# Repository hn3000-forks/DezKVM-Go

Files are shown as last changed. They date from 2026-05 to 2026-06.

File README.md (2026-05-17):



# DezKVM-Go

A mini KVM over USB device for onsite engineers to use their laptop to control headless computers or servers.

If you are looking for an IP-KVM solution, take a look at the [DezKVM](https://github.com/tobychui/DezKVM) Project!

## Features

- Small form factor , just 84 x 53 x 18mm
- Cheap & Easy to build, costing just under $20 USD per unit
- Fully featured software that do not require installing any apps
  - Live video and audio feeds
  - Paste box (host to remote computer through automatic virtual keyboard HID events)
  - Copy via OCR (remote to host computer through OCR image to text conversion) 
  - On-screen keyboard
  - Commonly used Hot-key and macros
  - Take Screenshots
- Advanced Settings
  - Invert mouse scroll wheel direction (for Windows / MacOS cross control)
  - Absolute / Relative mode for mouse
  - Mouse Jiggler
  
## Usage

1. Insert the DezKVM-Go host side USB port into your laptop using a USB type-C cable (located on the white / black side, depends on your device casing color)
2. Insert the DezKVM-Go remote side USB port and HDMI port into the remote server or computer you want to control (located on the orange side)
3. Visit the [DezKVM-Go control panel](https://tobychui.github.io/DezKVM-Go/) or if you are working online, start the usbkvm application and visit `https://localhost:8443/` using Chrome, Edge or any Chromium browsers that support Web-Serial API.

## Quick Start



## Building the Hardware

To build the hardware, you will need the following items

- A DezKVM-Go PCB (See the `PCB` folder and the `how-to-place-order` folder on how to order them )
  
- A MS2109 HDMI capture card (usually around $7 - 9 USD a pcs)
- A 3D printer (for the case, see `3D Models` folder)
- M3x10 screws x 2
- USB type-C cable x 2 and HDMI cable x 1

For details, see the PCB folder.

## Building the Software

There is no need to build anything since all of the control code of this system is written in vanilla js in the web front-end. However, this project do come with a Golang written https server in which if you have difficulties deploying a website with https , you can use that https server to deploy a locally hosted version of the DezKVM viewer.

To build the local version of DezKVM viewer, follow the instruction below.

```bash
cd ./src
go mod tidy
go build
```

*Note: you will also need to configure the CH9329 chip to use the 115200 baudrate for the front-end to work. Please follow the instructions in CH9329 datasheet to perform the baudrate change procedures before use.*

## Screenshots









[See more screenshots](https://github.com/tobychui/DezKVM-Go/wiki/Screenshots)

## DezKVM-Go Device

Here are a few photos on the device itself if you are interested.













### Generation 2 (MS2109S)

Due to shortage of MS2109, the HDMI capture card market are slowly shifting towards a new design of such capture card that uses MS2109S  (looks identical to the old MS2109 one, so it is hard to tell by just looking at the case of it),

In case you bought a HDMI capture card and realize it didn't fit because it is a MS2109S device, you can unscrew the metal case and use the bare PCB directly. Installation methods are as follows (notes: an additional 3D printed part and 3 x M2 x 5 screws are needed)

gen2-diff

### Buy a Ready-to-use Device

If you’d rather skip the build, I’ve put together some DezKVM Go devices that are ready to go. 

You can find them on my Tindie store (limited availability):

https://www.tindie.com/products/tobychui/dezkvm-go-kvm-over-usb-device/

## License

Software: GPLv3

Hardware: CC BY-NC-ND

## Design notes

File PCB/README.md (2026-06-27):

## Making your own DezKVM-GO Hardware

Making your DezKVM Go hardware is not difficult. What you need is to send the PCB to print. If you have the budget, you can even go the full PCBA route and make a ready to use product with the help of [NextPCB](https://www.nextpcb.com/?code=tobychui/C) (sponsor of this project)

### PCB Photoshoots







That cutout is for the MS2109 HDMI capture card. You can easily find one on Amazon for around 9 - 12USD. After inserting the capture card, the whole circuit should looks like this.





### What PCB manufacturing parameters should I pick?

Here are the parameters and properties I pick for making the PCB above. You can upload the Gerber file to [NextPCB](https://www.nextpcb.com/?code=tobychui/C) website and following the options in the screenshot below to make yours.











For details, see the BOM list and Gerber files.

## PCB v2

The v2 PCB is a refershed design of the original DezKVM-Go PCB but with the following updates

- Added hardware mode bit override pads
- Updated crystal package (so now it is JLC compatible)
- Added another internal downstream USB 2.0 port

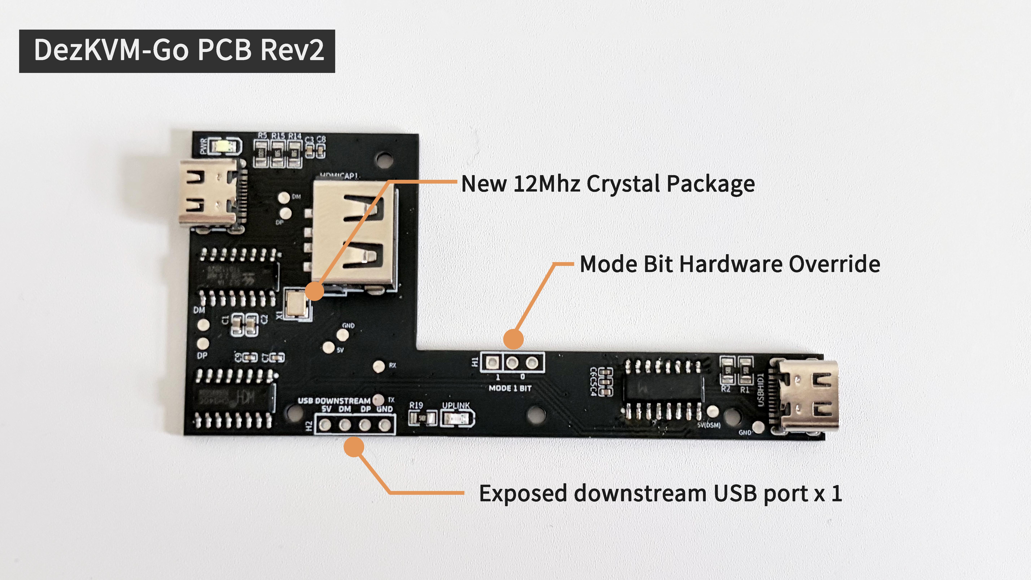
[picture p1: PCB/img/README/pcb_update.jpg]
pcb_update


This board have the exact form factor of the v1, so you can use it in gen1 - 3 3D printed case or assembly methods.

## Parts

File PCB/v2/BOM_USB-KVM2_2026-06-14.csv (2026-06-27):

ID | Name | Designator | Footprint | Quantity | Manufacturer Part | Manufacturer | Supplier | Supplier Part | Price
1 | 10uF | C1,C2 | C0603 | 2 | CL10A106KP8NNNC | SAMSUNG(三星) | LCSC | C19702 | 0.017
2 | whiteLEDSMD | PWR | LED0805-R-RD | 1 | KT-0805W | KENTO | LCSC | C34499 | 0.02
3 | 0805G (Green) | UPLINK | LED0805-R-RD | 1 | KT-0805G | KENTO | LCSC | C2297 | 0.016
4 | XY PZ2.54-1X4P ZD | H2 | CONN-TH_PZ2.54-1X4-11.2 | 1 | XY PZ2.54-1x4P ZD | XYECONN(辛译) | LCSC | C54110161 | 0.016
5 | 10uF | C3,C4 | C0402 | 2 | CL05A106MQ5NUNC | SAMSUNG(三星) | LCSC | C15525 | 0.019
6 | 100nF | C5,C6,C7,C8,C9 | C0402 | 5 | CL05B104KO5NNNC | SAMSUNG(三星) | LCSC | C1525 | 0.002
7 | 12MHz | X1 | CRYSTAL-SMD_4P-L3.2-W2.5-BL | 1 | X322512MSB4SI | YXC(扬兴晶振) | LCSC | C9002 | 0.101
8 | XY-2.54-1*3PZ | H1 | HDR-TH_XY-2.54-1X3PZ | 1 | XY-2.54-1*3PZ | XYECONN(辛译) | LCSC | C54110157 | 0.013
9 | CH340C | CH340C | SOP-16_L10.0-W3.9-P1.27-LS6.0-BL | 1 | CH340C | WCH(南京沁恒) | LCSC | C84681 | 0.586
10 | SL2.1A | US_HUB1 | SOP-16_L10.0-W3.9-P1.27-LS6.0-BL | 1 | SL2.1A | CoreChips(和芯润德) | LCSC | C192893 | 0.235
11 | KH-AF90QCSMT-10-H6.3 | HDMICAP1 | USB-A-SMD_KH-AF90QCSMT-10-H6.3 | 1 | KH-AF90QCSMT-10-H6.3 | kinghelm(金航标) | LCSC | C2979063 | 0.026
12 | 5.1kΩ | R1,R2,R14,R15,R19 | R0805 | 5 | 0805W8F5101T5E | UNI-ROYAL(厚声) | LCSC | C27834 | 0.003
13 | 1kΩ | R5 | R0805 | 1 | 0805W8F1001T5E | UNI-ROYAL(厚声) | LCSC | C17513 | 0.003
14 | CH9329 | U1 | SOP-16_L9.9-W3.9-P1.27-LS6.0-BL | 1 | CH9329 | WCH(南京沁恒) | LCSC | C2838834 | 1.305
15 | USB3.1C16PFSMT | USB-HOST1,USBHID1 | USB-C-SMD_TYPE-C-USB-17 | 2 | 918-418K2023S40001 | 精拓金 | LCSC | C167321 | 0.394

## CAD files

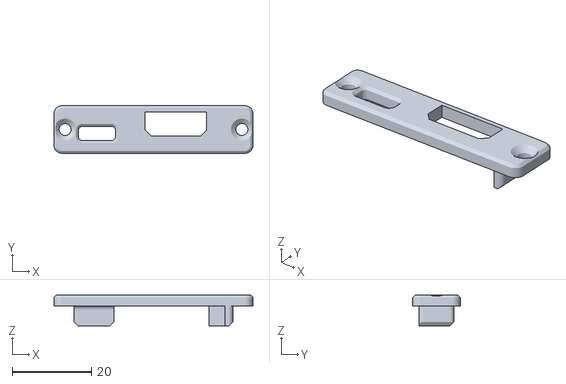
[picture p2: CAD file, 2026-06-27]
3D Models/gen3/coverv2.stl
50.2 x 12.0 x 7.80

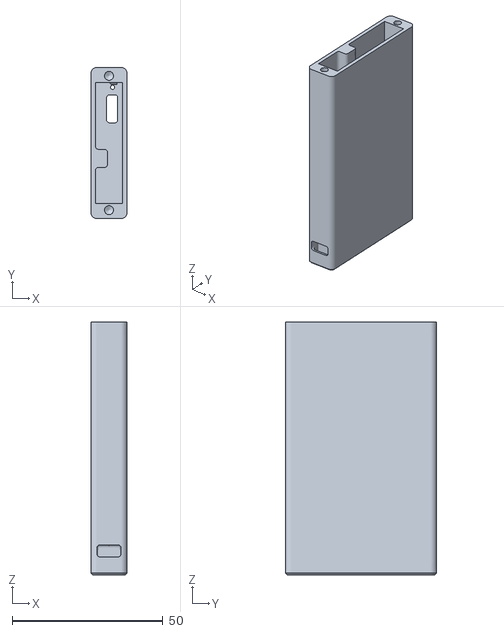
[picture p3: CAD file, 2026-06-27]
3D Models/gen3/casev2.stl
12.0 x 50.2 x 84.0

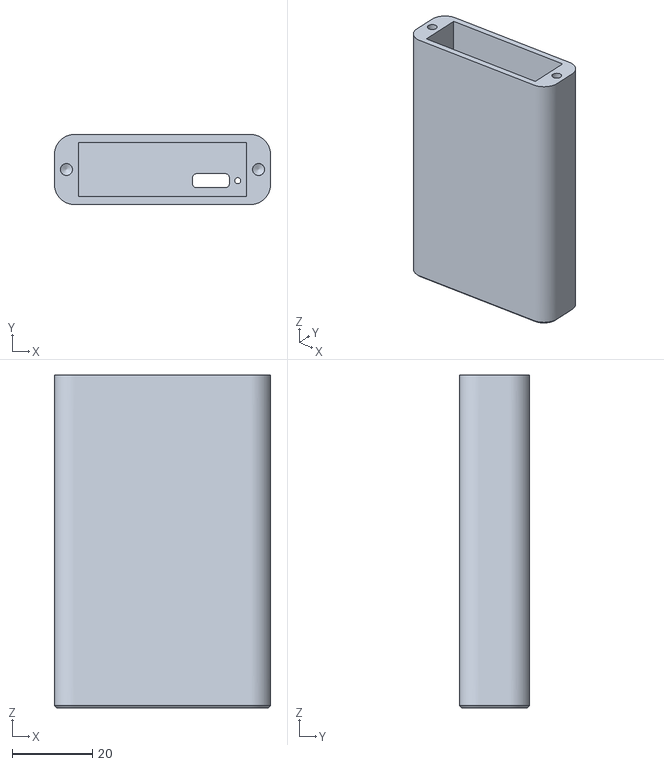
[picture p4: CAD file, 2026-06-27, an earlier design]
3D Models/gen1/base.stl
54.0 x 17.5 x 83.2

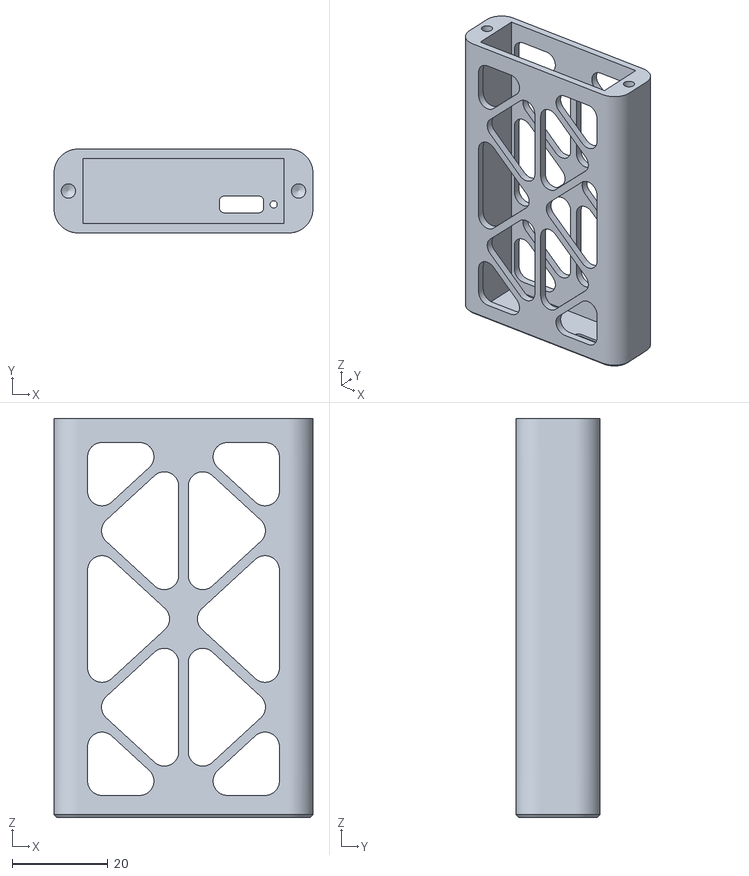
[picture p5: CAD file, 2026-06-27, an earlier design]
3D Models/gen1/base-open-frame.stl
54.0 x 17.5 x 83.2

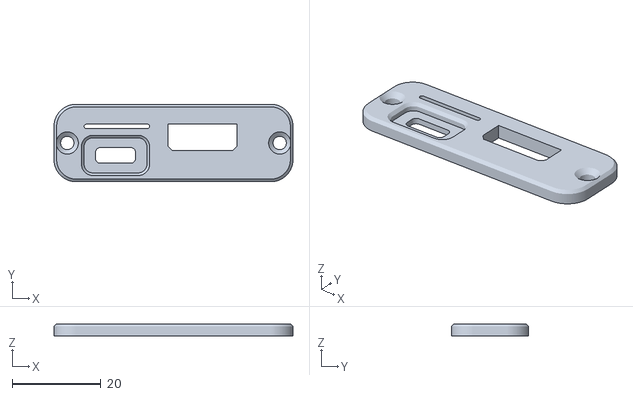
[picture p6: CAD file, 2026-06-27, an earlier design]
3D Models/gen2/cover-gen2.stl
54.0 x 17.5 x 2.80

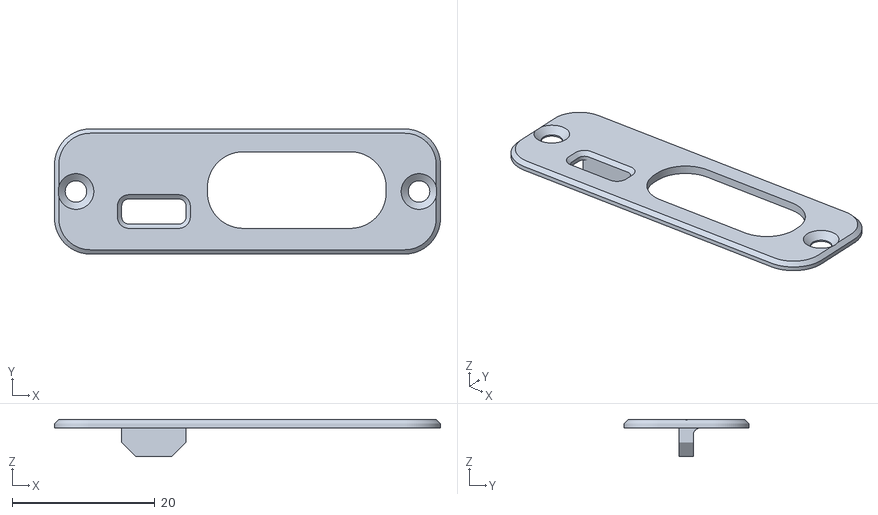
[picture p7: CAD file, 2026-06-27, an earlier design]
3D Models/gen1/cover.stl
54.0 x 17.5 x 5.20

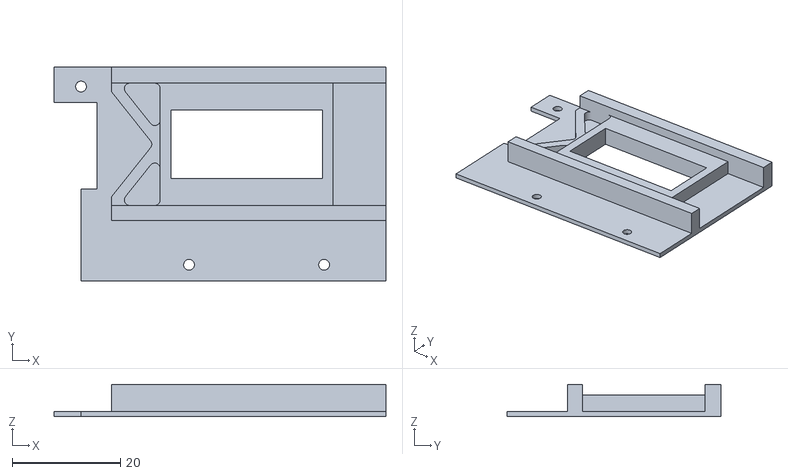
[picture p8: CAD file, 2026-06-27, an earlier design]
3D Models/gen2/gen2-hdmi-mount.stl
61.5 x 39.6 x 6.00

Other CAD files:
3D Models/gen1/base-open-frame.ipt
3D Models/gen1/base.ipt
3D Models/gen1/cover.ipt
3D Models/gen1/test_Fit.iam
3D Models/gen2/base.ipt
3D Models/gen2/cover-gen2.ipt
3D Models/gen2/gen2-hdmi-mount.ipt
3D Models/gen3/OldVersions/test_fitv2.0002.iam
3D Models/gen3/casev2.ipt
3D Models/gen3/coverv2.ipt
3D Models/gen3/test_fitv2.iam

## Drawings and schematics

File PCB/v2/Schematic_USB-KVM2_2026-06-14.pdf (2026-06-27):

# VBUS A4 CC1 A5 DP1 A6 DN1 A7 SBU1 A8 VBUS A9

## Power Ripple Filter

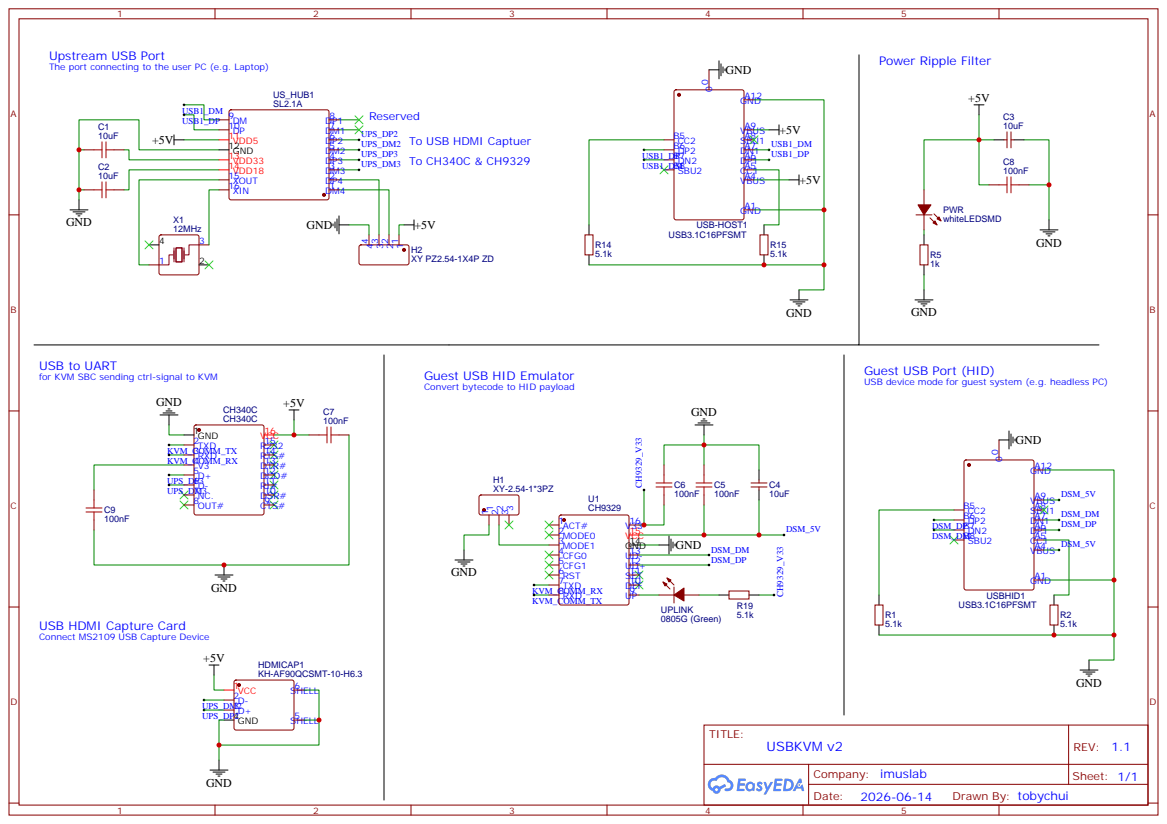
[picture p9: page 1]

Upstream USB Port
The port connecting to the user PC (e.g. Laptop)

Reserved
To USB HDMI Captuer

USB to UART
for KVM SBC sending ctrl-signal to KVM

Guest USB Port (HID) Guest USB HID Emulator
Convert bytecode to HID payload

USB device mode for guest system (e.g. headless PC)

DSR# 10 RI#11 DCD# 12 DTR# 13 RTS# 14 R232 15 VCC 16

DEF 10 SET 11 UD+ 12 UD- 13 GND 14 VCC 15 V33 16

USB HDMI Capture Card
Connect MS2109 USB Capture Device

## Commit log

2026-06-27 Add v2 PCB reference design
    [BOM_USB-KVM2_2026-06-14.csv, PickAndPlace_PCB_USB-KVM_2026-06-14.csv]
2026-06-27 Add gen3 case design
    - Added gen3 case design
    - Restructured the 3D model folder to better align with what product page versioning
    [base-open-frame.ipt, base-open-frame.stl, base.ipt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]
2026-07-02 better debugging of device list
2026-07-02 even better debugging, workaround for ChromeOS device labels
    (all my 2109 video capture devices have names like "USB Video")
